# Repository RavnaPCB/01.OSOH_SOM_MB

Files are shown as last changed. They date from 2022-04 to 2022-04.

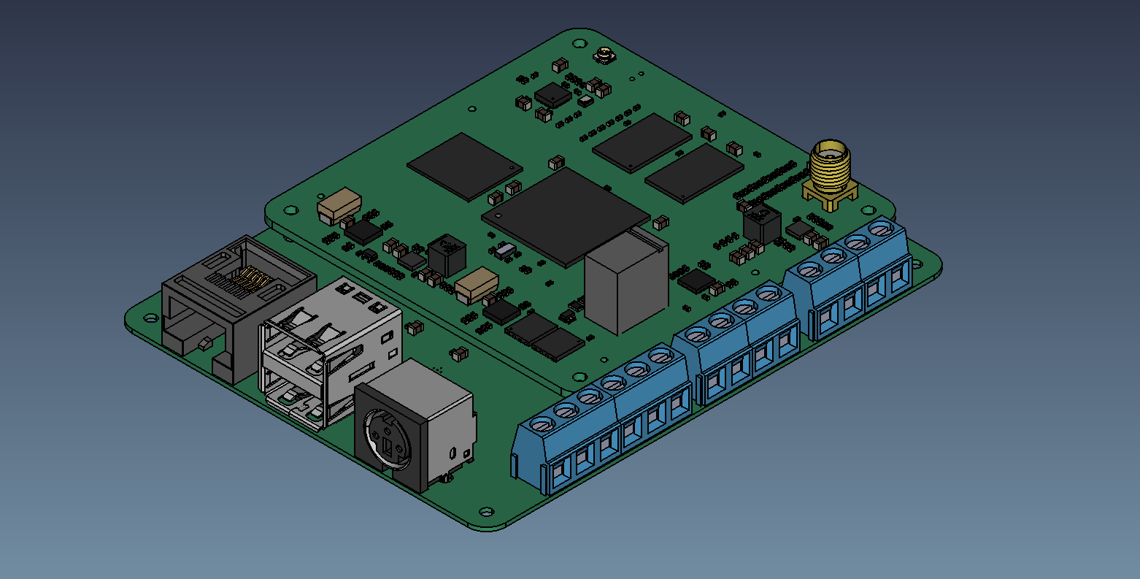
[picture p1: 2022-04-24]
1.3DCAD/Module_00.png

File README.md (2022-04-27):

## ReadME

    STM32MP157 SOM [DBSTM32MP1]               - [Work In Progress]
    
    STM32MP157 Motherboard [MB10080_STM32MP1] - [Work In Progress]
    
## Introduction

I started this project a few months ago, in order to learn PCB Design, and deepen my electronics knowledge, with the intention to eventually publicly release the development files, so other people could learn from them and my mistakes, and maybe at some point, after all the issues are sorted out - use as a reference or put to actual use.

## Future Plans

> Develop a series of robust [OpenHardware] Systems On Module [SOM], Motherboards and Single Board Computers [SBC] capable of operating in the industrial temperature range, accompanied by detailed circuit explanations, spreadsheets, simulations and repair manuals.

## Software Requirements [OpenSource]

[KiCAD](https://www.kicad.org/) - A Cross Platform and Open Source Electronics Design Automation Suite

[LibreOFFICE](https://www.libreoffice.org)  - Office Suite

[FreeCAD](https://www.freecadweb.org/)  - 3D Parametric Modeler

[FEMM](https://www.femm.info/wiki/Download) - Finite Element Method Magnetics

[CommonLIB](https://github.com/IvanIlievOSOH/00.CommonLIB) - Custom KiCAD Library

## Knows Issues, Flaws and Quirks

> The components I picked are not the best ones currently in production, nor the most suitable ones, but when I started this project a few months ago, I had the intention to get the PCBs manufactured and assembled, so I had to work with what was available on Mouser and Digikey, but since a complete redesign will be necessary to fix some of the issues and the ongoing chip shortage is still going strong, the next revision will be a major one, using other, more suitable components, not necessarily available at the moment from the official distributors. The boards will be manufactured and assembled when the semiconductor crisis is over unless I a way to source the components

> There are some things that don't make much sense at first glance (unused pads, holes in the solder mask, unnecessary components and copper pours etc). Most are there intentionaly because I wanted to do some measurements and experiments with the PCBs in order to prove some rules and concepts to myself.

> There are also some very obvious and probably critical "SI" and "PI" issues (Dual Stripline traces running parallel to eachother longer than they should, one of the eMMC Flash power rails routed as a relatively narrow trace on an outside layer etc.). I will be reporting and describing every issue I find in the repository's "Issues" tab.

> In hindsight, most of the issues and mistakes could have easily been avoided at an earlier stage of the design, if more research was done, but I decided to upload everything now, as a [Work In Progress], so I can hopefully get some constructive criticism and suggestoins before I start redesigning the boards.

    All your feedback, cirticism, help and suggestions will be greatly appreciated.



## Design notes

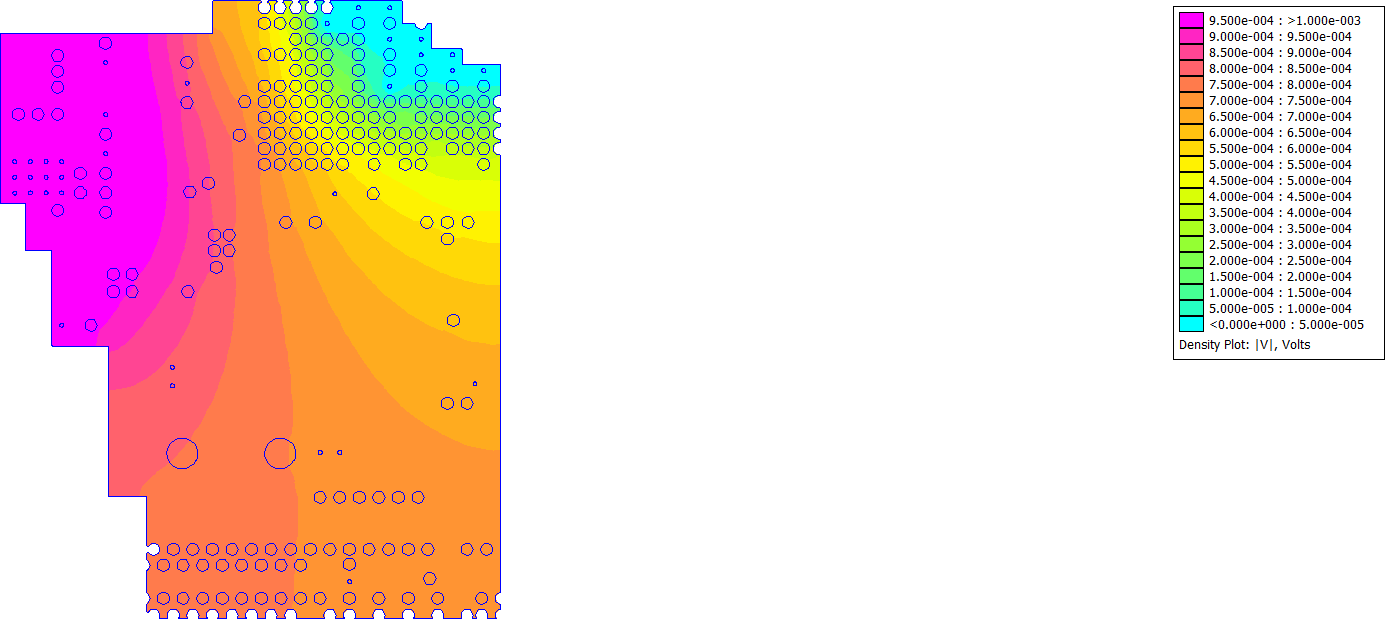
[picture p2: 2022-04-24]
1.DBSTM32MP1 [WIP]/Simulations/FEMM/VDD_CPU/Voltage_Drop.png

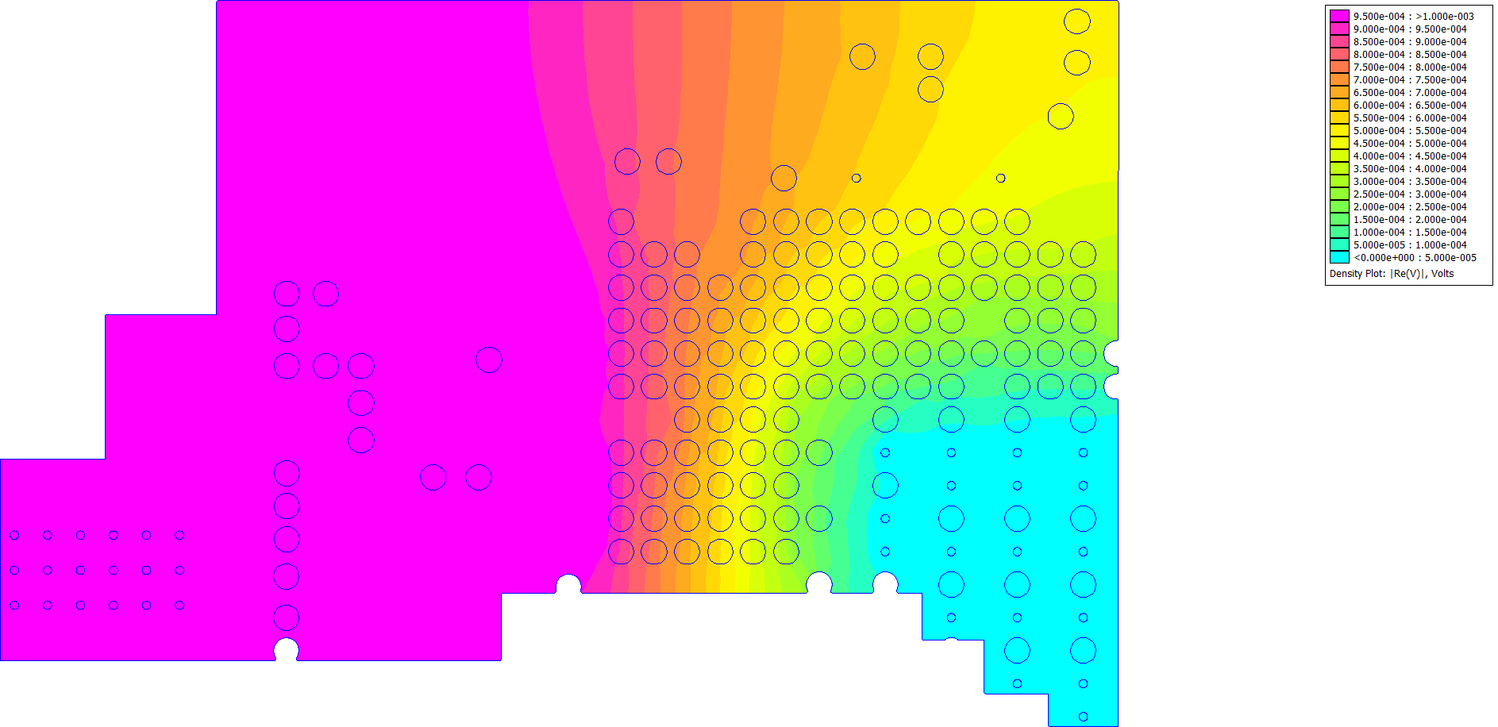
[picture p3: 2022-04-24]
1.DBSTM32MP1 [WIP]/Simulations/FEMM/VCORE/Voltage_Drop.png

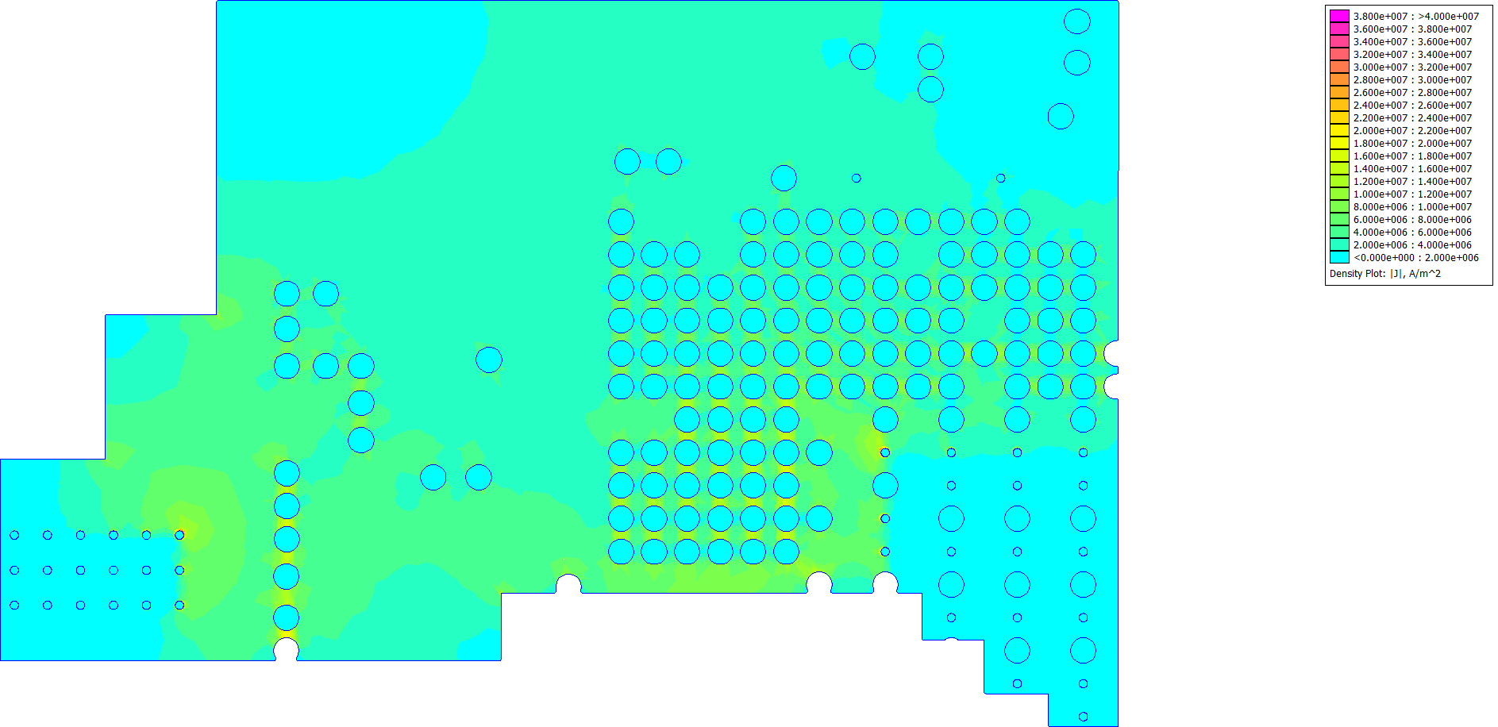
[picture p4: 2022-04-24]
1.DBSTM32MP1 [WIP]/Simulations/FEMM/VCORE/Current_Density.png

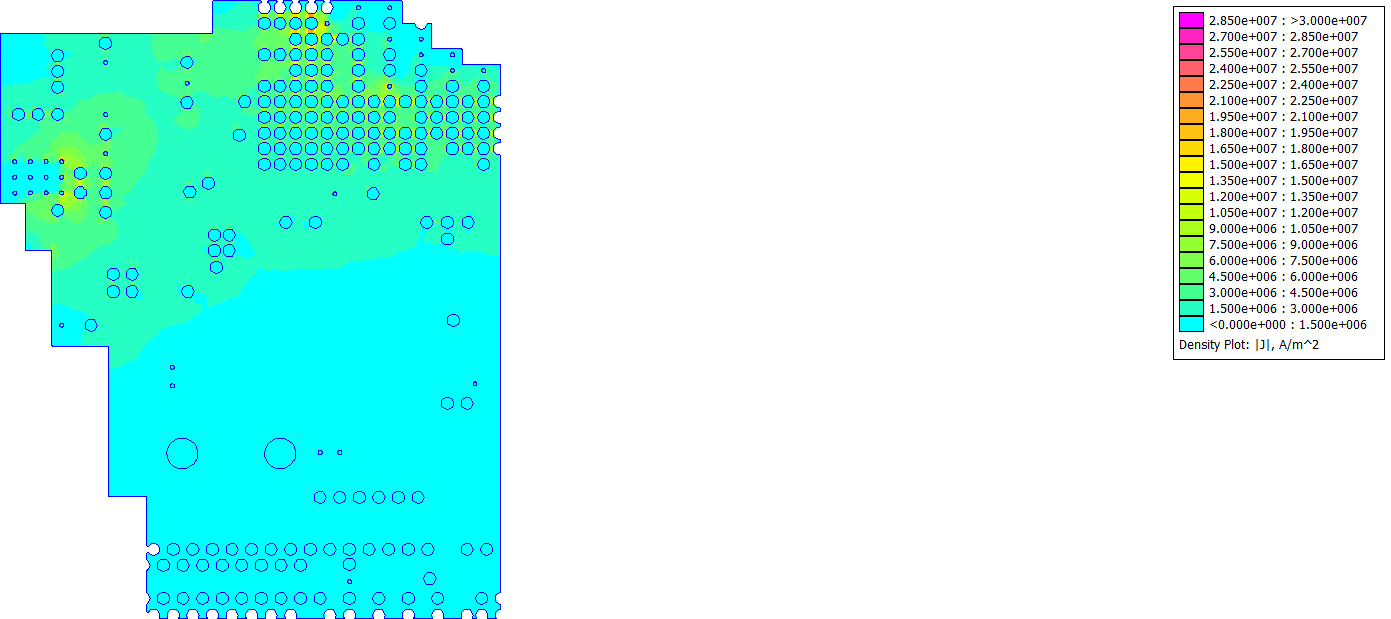
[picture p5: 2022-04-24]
1.DBSTM32MP1 [WIP]/Simulations/FEMM/VDD_CPU/Current_Density.png

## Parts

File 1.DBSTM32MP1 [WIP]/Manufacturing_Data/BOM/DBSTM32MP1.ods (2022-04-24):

Ref | Qnty | Value | Cmp name | Footprint | Description
C100, C101, C102, C103, C120, C140, C141, C241, C242, C243, C270, C271, C272, C273, C300, C301, C302, C306, C332, C502, C512, C532, C542, C543, C611, C641, C700, C710, C800, | 29 | 10uF | C | 00.Common:C_0805 | C
C104, C105, C106, C107, C108, C109, C110, C111, C112, C113, C114, C115, C116, C130, C131, C132, C133, C134, C135, C136, C142, C143, C144, C145, C146, C147, C148, C149, C150, C151, C152, C153, C154, C303, C304, C305, C307, C330, C331, C340, C400, C460, C462, C480, C520, C580, C601, C602, C612, C613, C642, C651, C701, C801, | 54 | 1uF | C | 00.Common:C_0402 | C
C200, C201, C202, C203, C204, C205, C206, C207, C208, C209, C210, C211, C212, C213, C220, C221, C222, C223, C224, C225, C226, C227, C228, C229, C230, C231, C232, C233, C240, C250, C251, C252, C253, C254, C255, C256, C257, C258, C259, C260, C261, C262, C263, C264, C265, C266, C267, C341, C350, C351, C352, C353, C354, C355, C356, C370, C371, C372, C373, C374, C375, C376, C377, C378, C379, C380, C381, C382, C383, C384, C385, C386, C387, C388, C389, C390, C391, C392, C393, C461, C470, C490, C491, C503, C504, C513, C514, C515, C521, C522, C533, C534, C544, C545, C546, C547, C581, C582, C603, C614, C615, C621, C643, C644, C652, C653, C702, C703, C704, C711, C712, C713, C714, C721, C751, C752, C760, C761, C780, C802, C803, C810, | 122 | 100nF | C | 00.Common:C_0402 | C
C310, C311, C820, C830, | 4 | C | C | 00.Common:C_0402 | C
C357, C360, | 2 | 2.2uF | C | 00.Common:C_0805 | C
C430, C431, | 2 | 6.8pF | C | 00.Common:C_0402 | C
C440, C620, C660, C720, C770, | 5 | 10nF | C | 00.Common:C_0402 | C
C450, | 1 | 47mF | CP | 00.Common:FM0H104ZF | CP
C500, C530, C540, | 3 | 22uF | CP | 00.Common:C_2312 | CP
C501, C510, C511, C531, C541, C610, C650, | 7 | 22uF | C | 00.Common:C_0805 | C
C523, C583, | 2 | 3.3nF | C | 00.Common:C_0402 | C
C600, C640, | 2 | 10uF | CP | 00.Common:C_2312 | CP
C750, | 1 | 4.7uF | C | 00.Common:C_0805 | C
D420, | 1 | RED | LED | 00.Common:LED_0402
D421, | 1 | BLUE | LED | 00.Common:LED_0402
D500, D530, | 2 | D | D | 00.Common:D_0402 | D
J1, J2, | 2 | Connector_1x2 | Connector_1x2 | 00.Common:1x02_Connector_2mm_Vertical_THT | Connector_1x2
J3, | 1 | Coax | Coax | 00.Common:CONUFL001-SMD-T | Connector_Coax
J4, | 1 | uSD | uSD | 00.Common:uSD_693072010801 | uSD
J5, | 1 | Coax | Coax | 00.Common:SMA_132134-10 | Connector_Coax
J6, J8, | 2 | FX10A-120S-P-SV | FX10A-120S-P-SV | 00.Common:FX10A-120S-P-SV | FX10A-120S-P-SV
J7, | 1 | Connector_2x5 | Connector_2x5 | 00.Common:2x05_Connector_1.00_Vertical_SMD | Connector_2x5
L300, | 1 | 4.7uH | L | 00.Common:C_0805 | L
L310, | 1 | L | L | 00.Common:C_0402 | L
L460, | 1 | 4.7uH | L | 00.Common:R_0805 | L
L500, L530, | 2 | 1.4uH | L | 00.Common:XGL_4040 | L
Q500, | 1 | N_MOSFET | N_MOSFET | 00.Common:SOT-323_SC-70
R200, R201, R202, R203, R204, R205, R206, R207, R208, R209, R210, R211, R212, R213, R214, R215, R216, R217, R218, R219, R220, R221, R222, R223, | 24 | 56R | R | 00.Common:R_0402 | R
R224, R225, R330, R340, R350, R351, R352, R353, R750, | 9 | 10K | R | 00.Common:R_0402 | R
R226, R620, | 2 | 100R | R | 00.Common:R_0402 | R
R240, R241, R242, | 3 | 240R | R | 00.Common:R_0402 | R
R300, | 1 | 50R | R | 00.Common:R_0402 | R
R331, R354, | 2 | 22R | R | 00.Common:R_0402 | R
R332, R355, R400, R402, R403, R405, R406, R408, R409, R410, R411, R412, R430, R431, R442, R470, R471, R500, R504, R640, R803, R900, | 22 | 0R | R | 00.Common:R_0402 | R
R401, R404, R407, R440, | 4 | 1K | R | 00.Common:R_0402 | R
R420, R421, | 2 | 220R | R | 00.Common:R_0402 | R
R441, | 1 | 10R | R | 00.Common:R_0402 | R
R450, R451, R452, R460, | 4 | 0R | R | 00.Common:R_0805 | R
R480, | 1 | 3K | R | 00.Common:R_0402 | R
R490, R491, R492, R493, R494, R495, | 6 | 1.5K | R | 00.Common:R_0402 | R
R501, R502, R503, R530, R531, R532, R621, R622, R641, R642, R721, R722, R751, R752, | 14 | 100K | R | 00.Common:R_0402 | R
R720, | 1 | R100 | R | 00.Common:R_0402 | R
R800, R801, | 2 | R | R | 00.Common:R_0402 | R
U1, U2, | 2 | RT6206 | RT6206 | 00.Common:WDFN-10L-3x3 | RT6206
U3, U4, U5, | 3 | LP38798 | LP38798 | 00.Common:WSON-12_4x4 | LP38798
U6, | 1 | LP3878-ADJ | LP3878-ADJ | 00.Common:WSON-8-4x4 | LP3878
U7, | 1 | LP2998 | LP2998 | 00.Common:DFN-10-1EP_3x3 | LP2998
U8, | 1 | WF200SD | WF200SD | 00.Common:QFN-32-4x4-P0.4 | WF200SD
U9, U16, | 2 | DDR3L | DDR3L | 00.Common:TF_BGA96
U10, U11, | 2 | WSON-8-6x5-FLASH | WSON-8-6x5-FLASH | 00.Common:WSON-8-6x5 | WSON-8-6x5-FLASH
U12, | 1 | STM32MP157AAA3 | STM32MP1_BASE | 00.Common:STM32MP157AAA3 | STM32MP1_BASE
U13, U14, | 2 | AND_GATE | AND_GATE | 00.Common:SOT-353_SC-70-5 | AND_GATE
U15, | 1 | eMMC | eMMC | 00.Common:WFBGA153 | eMMC
X1, | 1 | 24.00 MHz | MEMS_OSC | 00.Common:OSC-3.2x2.5
Y2, | 1 | 32.768 KHz | 2P_OSC | 00.Common:OSC-3.2x1.5 | 2P_OSC
Y300, | 1 | 38.4 MHz | OSC_GND24 | 00.Common:OSC_2.0x1.6 | OSC_GND24

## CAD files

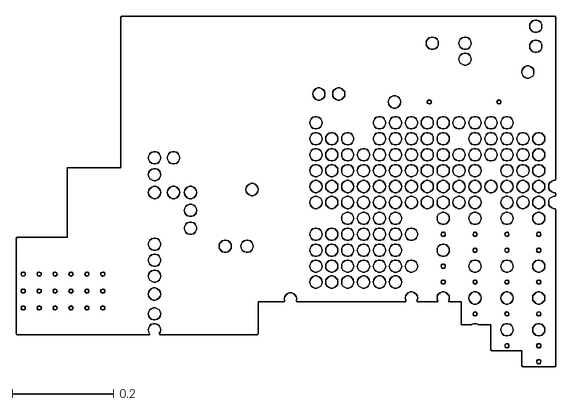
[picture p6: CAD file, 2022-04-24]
1.DBSTM32MP1 [WIP]/Simulations/DXF/DBSTM32MP1-VDD_CORE.dxf
1.07 x 0.693

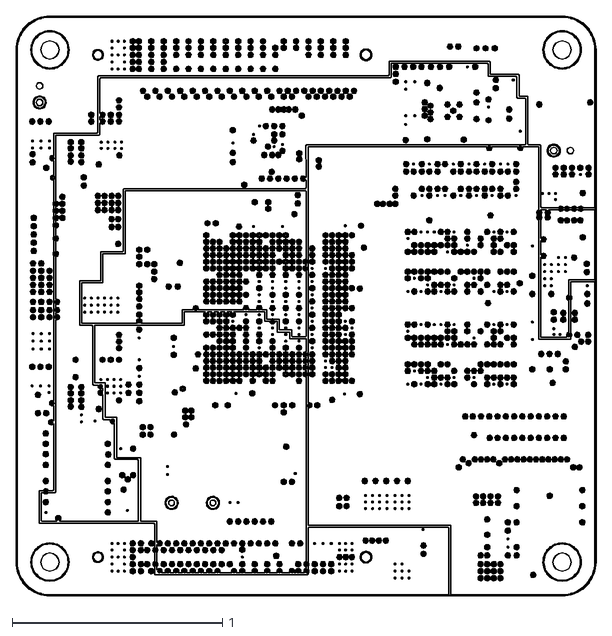
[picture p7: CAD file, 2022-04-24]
1.DBSTM32MP1 [WIP]/Simulations/DXF/DBSTM32MP1-VDD[RAW].dxf
2.76 x 2.76

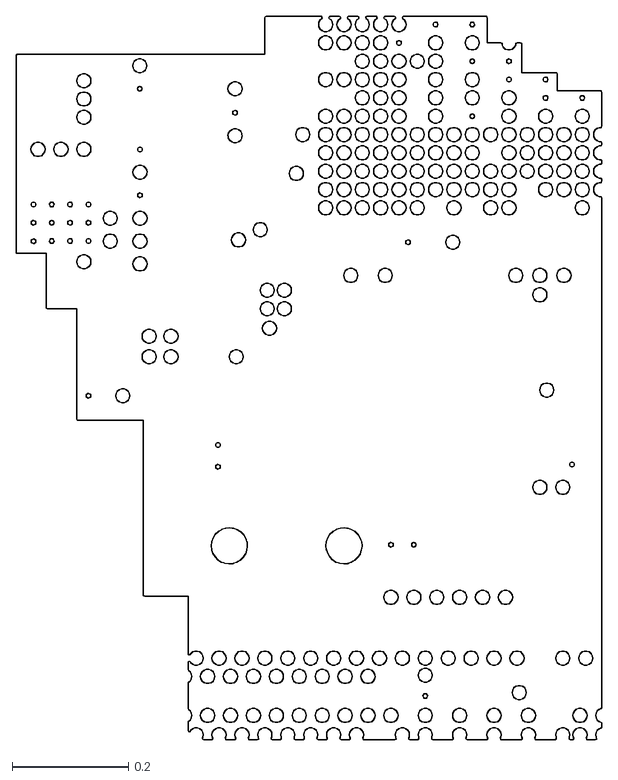
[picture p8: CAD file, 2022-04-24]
1.DBSTM32MP1 [WIP]/Simulations/DXF/DBSTM32MP1-VDD_CPU.dxf
1.01 x 1.24

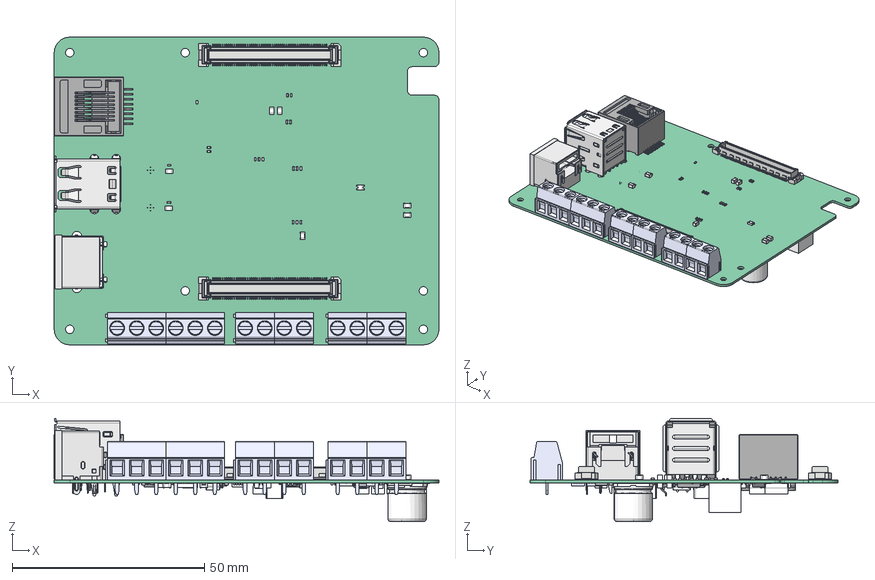
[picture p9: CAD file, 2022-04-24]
1.MB10080_STM32MP1 [WIP]/3DCAD/MB10080_STM32MP1.FCStd
100.1 x 80.0 x 26.8 mm
Pcb_820f
TB006-508-03P_Blue - S
TB006-508-03P_Blue - S001
C95_C_0402_1005Metric_89083f15f6f9
R26_R_0402_1005Metric_b49b6816676e
C103_C_0805_2012Metric_27ec9a05496c
C97_C_0805_2012Metric_ac6420e91872
R24_R_0402_1005Metric_b9c2278e08e6
C73_C_0402_1005Metric_77ea594f8db1
C101_C_0402_1005Metric_fdc04734f633
C30_C_0402_1005Metric_dc666e8bfdf3
TB006-508-02P_Blue - S
TB006-508-02P_Blue - S001
C99_C_0402_1005Metric_8ebc8eb86d38
C89_C_0402_1005Metric_ad1054f418c5
C12_C_0805_2012Metric_cb829bac7224
C27_C_0402_1005Metric_738307f9e339
C87_C_0402_1005Metric_293bc573aa11
C111_C_0805_2012Metric_cfe71d9d4230
J8_FX10A-120P-SV_b29a9b1ca1f1
C114_C_0402_1005Metric_6f66377c607f
CUI_DEVICES_MD-30SM
CUI_DEVICES_MD-30SM001
CUI_DEVICES_MD-30SM002
CUI_DEVICES_MD-30SM003
CUI_DEVICES_MD-30SM004
CUI_DEVICES_MD-30SM005
C96_C_0805_2012Metric_dac484ff7f15
C115_C_0402_1005Metric_cd8c7d194291
C88_C_0805_2012Metric_c22c037c54e6
TB006-508-02P_Blue - S002
TB006-508-02P_Blue - S003
J9_(Unsaved)_836c44e12b4a
D2_D_0805_3bacf84006ee
C94_C_0402_1005Metric_d5e17bd9bb97
C106_C_0402_1005Metric_816197e5a8a8
(Unsaved)
(Unsaved)001
(Unsaved)002
(Unsaved)003
(Unsaved)004
(Unsaved)005
(Unsaved)006
(Unsaved)007
(Unsaved)008
(Unsaved)009
(Unsaved)010
(Unsaved)011
(Unsaved)012
(Unsaved)013
(Unsaved)014
(Unsaved)015
(Unsaved)016
(Unsaved)017
(Unsaved)018
(Unsaved)019
C113_C_0402_1005Metric_2f24029c02ec
C71_C_0402_1005Metric_c18872e2a6e8
R25_R_0402_1005Metric_be235fa08f4c
C36_C_0402_1005Metric_1dce11c8cb39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

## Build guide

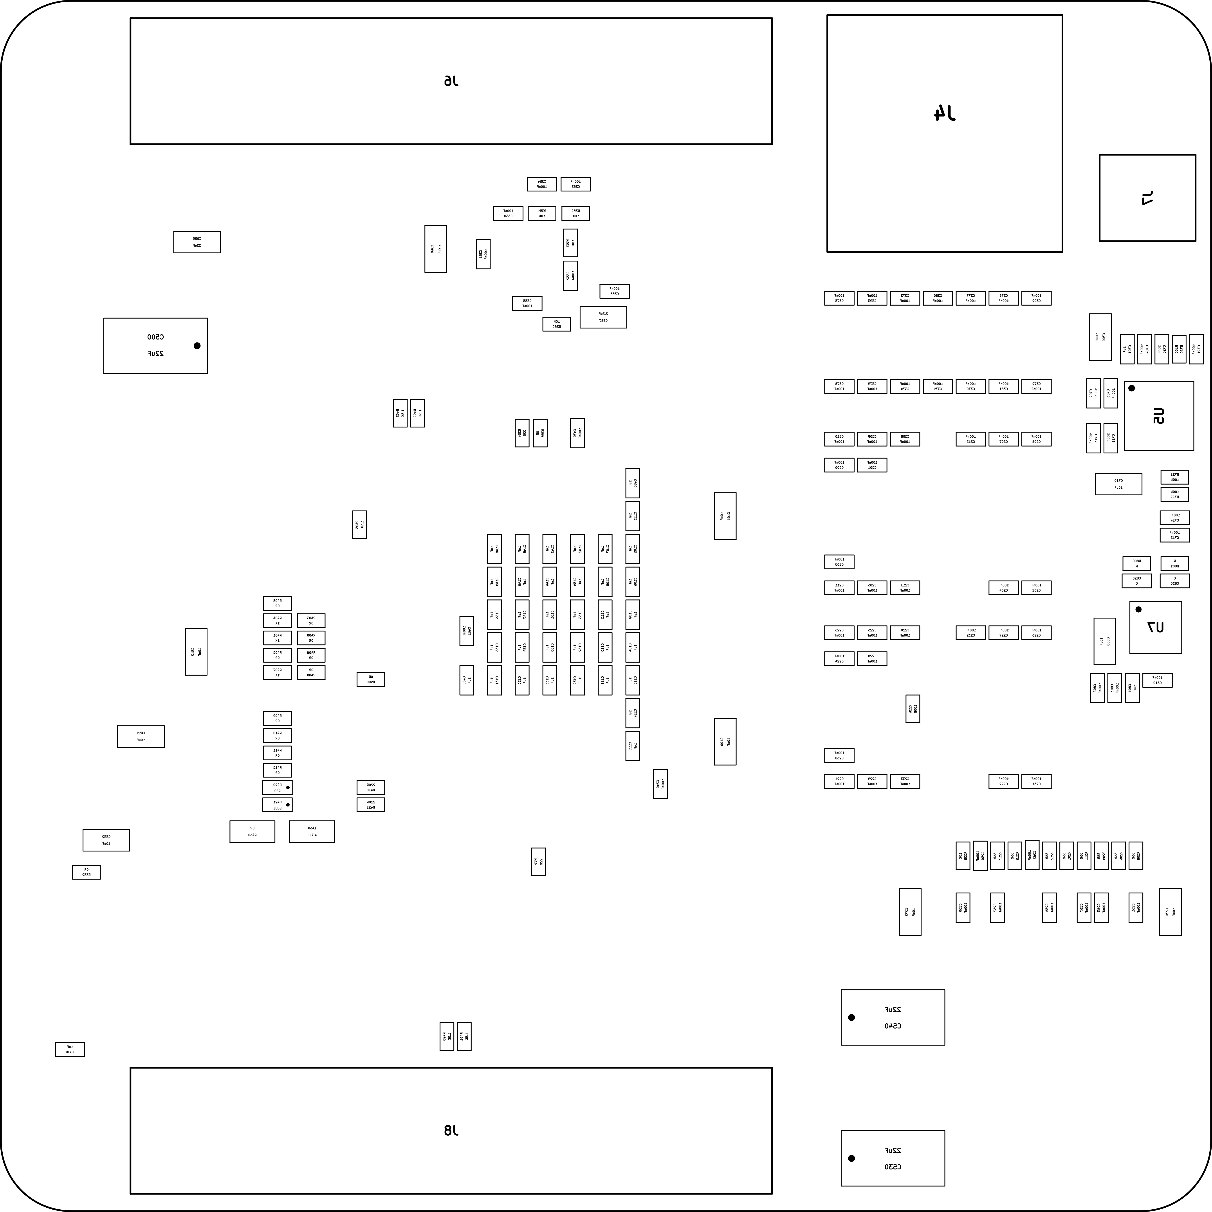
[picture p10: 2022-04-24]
1.DBSTM32MP1 [WIP]/Manufacturing_Data/ASSEMBLY/DBSTM32MP1-B_Fab.png

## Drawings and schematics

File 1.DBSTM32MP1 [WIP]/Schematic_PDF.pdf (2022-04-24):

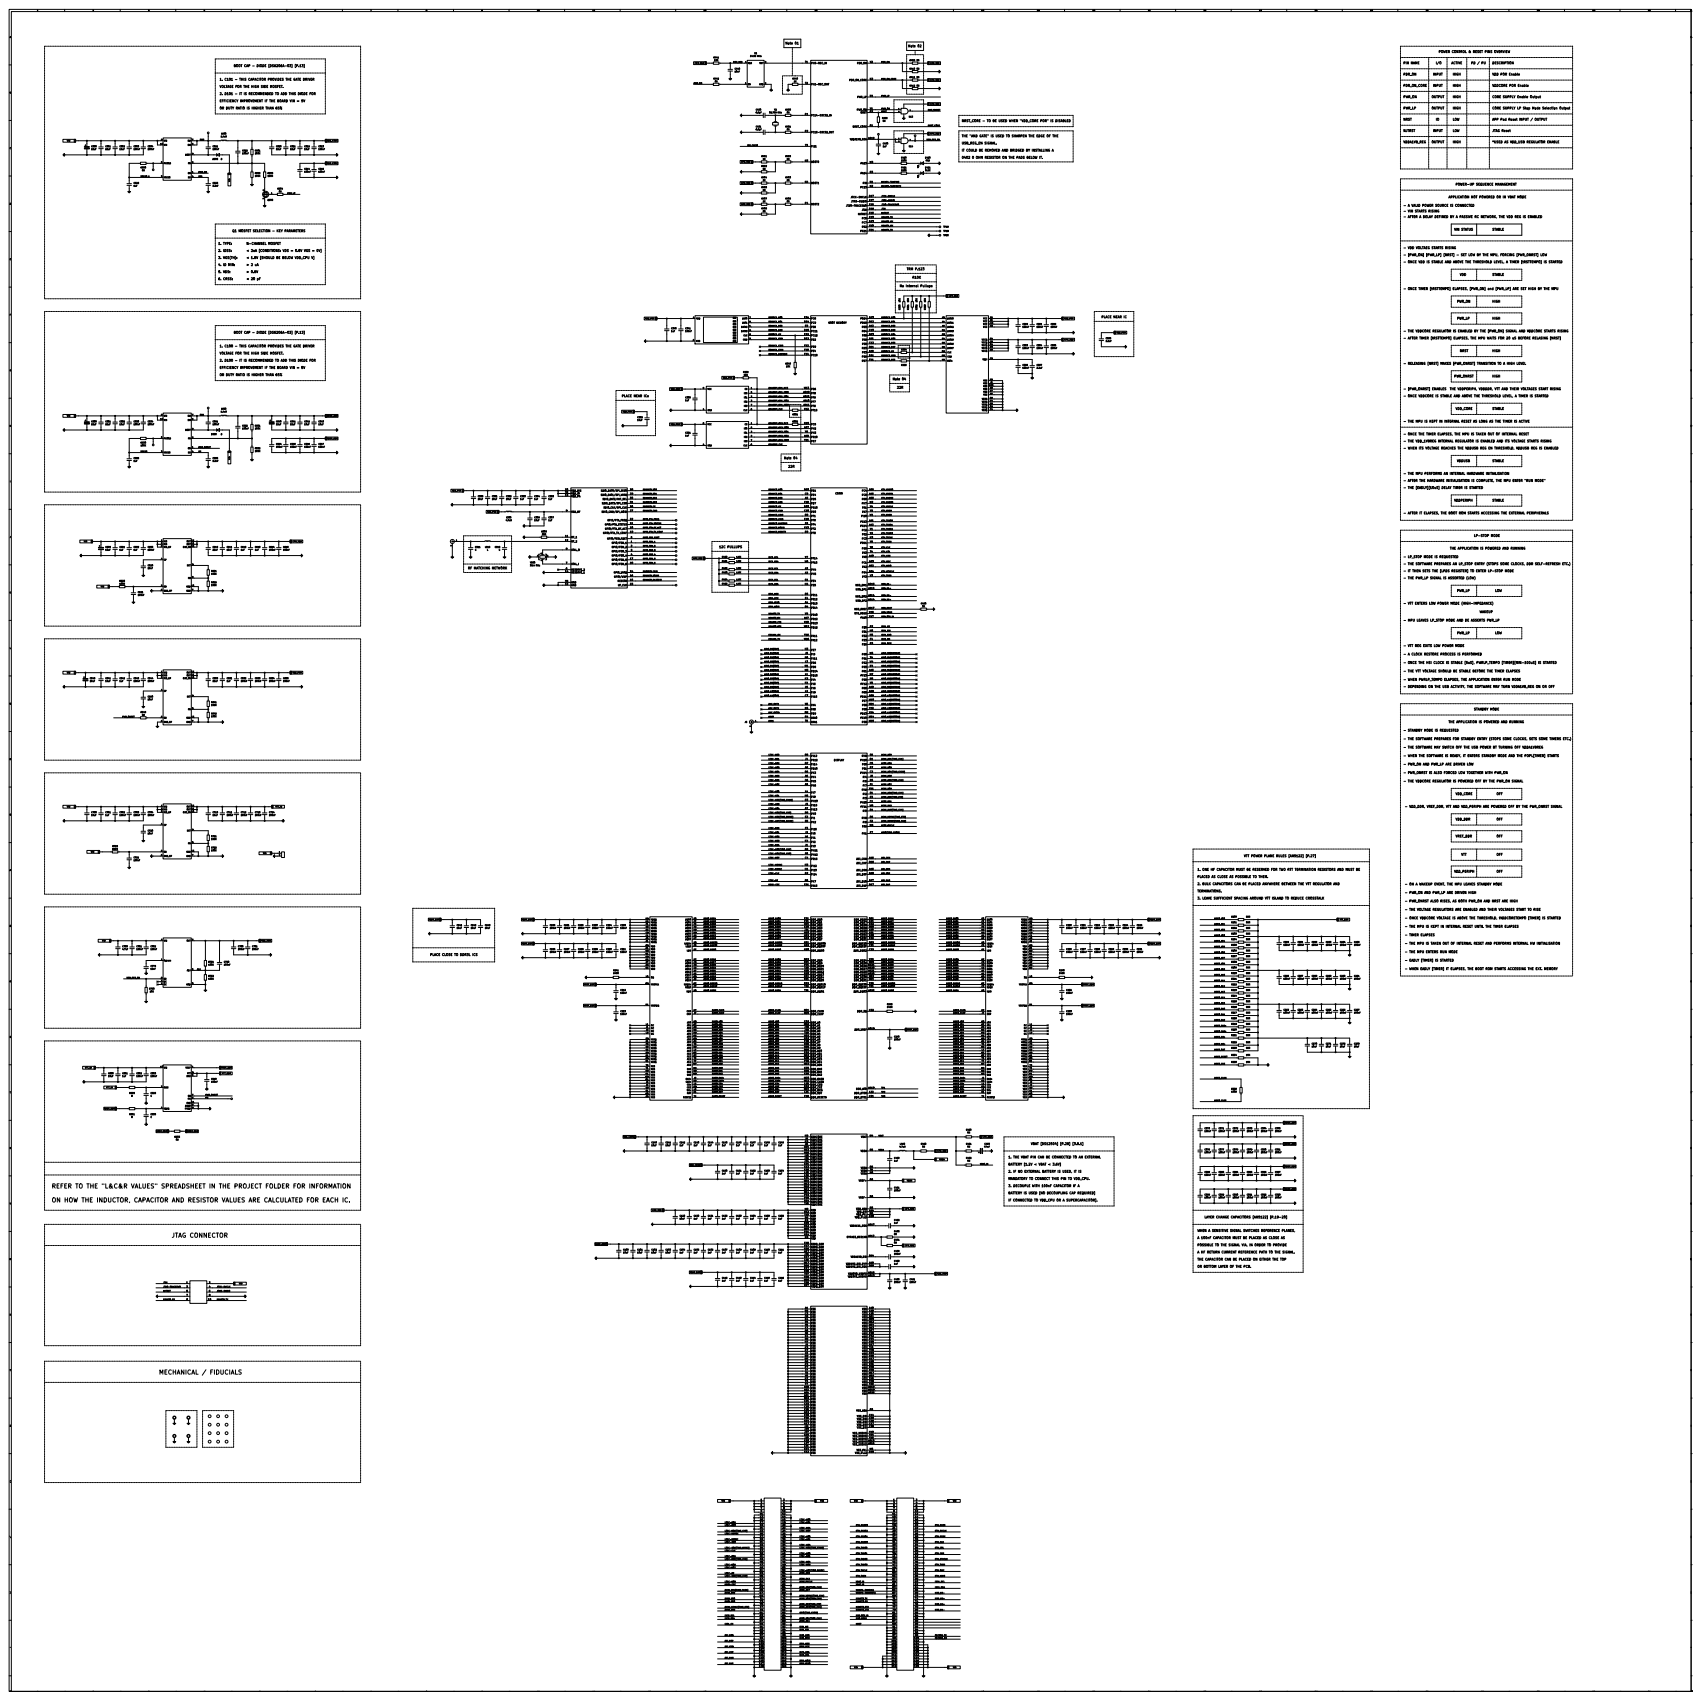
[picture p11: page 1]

POWER CONTROL & RESET PINS OVERVIEW

1. C101 - THIS CAPACITOR PROVIDES THE GATE DRIVER

VOLTAGE FOR THE HIGH SIDE MOSFET.

2. D101 - IT IS RECOMMENDED TO ADD THIS DIODE FOR

CORE SUPPLY Enable Output

EFFICIENCY IMPROVEMENT IF THE BOARD VIN = 5V

OR DUTY RATIO IS HIGHER THAN 65%

CORE SUPPLY LP Stop Mode Selection Output

APP Pad Reset INPUT / OUTPUT

NRST_CORE - TO BE USED WHEN "VDD_CORE POR" IS DISABLED

THE "AND GATE" IS USED TO SHARPEN THE EDGE OF THE

*USED AS VDD_USB REGULATOR ENABLE

IT COULD BE REMOVED AND BRIDGED BY INSTALLING A

0402 0 OHM RESISTOR ON THE PADS BELOW IT.

POWER-UP SEQUENCE MANAGEMENT

APPLICATION NOT POWERED OR IN VBAT MODE

- A VALID POWER SOURCE IS CONNECTED
- VIN STARTS RISING
- AFTER A DELAY DEFINED BY A PASSIVE RC NETWORK, THE VDD REG IS ENABLED

Q1 MOSFET SELECTION - KEY PARAMETERS

- VDD VOLTAEG STARTS RISING

- ONCE VDD IS STABLE AND ABOVE THE THRESHOLD LEVEL, A TIMER [tRSTTEMPO] IS STARTED

- ONCE TIMER [tRSTTEMPO] ELAPSES, [PWR_ON] and [PWR_LP] ARE SET HIGH BY THE MPU

- THE VDDCORE REGULATOR IS ENABLED BY THE [PWR_ON] SIGNAL AND VDDCORE STARTS RISING
- AFTER TIMER [tRSTTEMPO] ELAPSES, THE MPU WAITS FOR 20 uS BEFORE RELASING [NRST]

1. C100 - THIS CAPACITOR PROVIDES THE GATE DRIVER

2. D100 - IT IS RECOMMENDED TO ADD THIS DIODE FOR

- RELEASING [NRST] MAKES [PWR_ONRST] TRANSITION TO A HIGH LEVEL

- [PWR_ONRST] ENABLES THE VDDPERIPH, VDDDDR, VTT AND THEIR VOLTAGES START RISING
- ONCE VDDCORE IS STABLE AND ABOVE THE THRESHOLD LEVEL, A TIMER IS STARTED

- THE MPU IS KEPT IN INTERNAL RESET AS LONG AS THE TIMER IS ACTIVE

- ONCE THE TIMER ELAPSES, THE MPU IS TAKEN OUT OF INTERNAL RESET
- THE VDD_1V8REG INTERNAL REGULATOR IS ENABLED AND ITS VOLTAGE STARTS RISING
- WHEN ITS VOLTAGE REACHES THE VDDUSB REG EN THRESHOLD, VDDUSB REG IS ENABLED

- THE MPU PERFORMS AN INTERNAL HARDWARE INITIALISATION
- AFTER THE HARDWARE INITIALISATION IS COMPLETE, THE MPU ENTER "RUN MODE"
- THE [EADLY][10uS] DELAY TIMER IS STARTED

- AFTER IT ELAPSES, THE BOOT ROM STARTS ACCESSING THE EXTERNAL PERIPHERALS

THE APPLICATION IS POWERED AND RUNNING

- LP_STOP MODE IS REQUESTED
- THE SOFTWARE PREPARES AN LP_STOP ENTRY (STOPS SOME CLOCKS, DDR SELF-REFRESH ETC.)
- IT THEN SETS THE [LPDS REGISTER] TO ENTER LP-STOP MODE
- THE PWR_LP SIGNAL IS ASSERTED (LOW)

- VTT ENTERS LOW POWER MODE (HIGH-IMPEDANCE)

- MPU LEAVES LP_STOP MODE AND DE ASSERTS PWR_LP

- VTT REG EXITS LOW POWER MODE

- A CLOCK RESTORE PROCESS IS PERFORMED

- ONCE THE HSI CLOCK IS STABLE [5uS], PWRLP_TEMPO [TIMER][MIN-100uS] IS STARTED

- THE VTT VOLTAGE SHOULD BE STABLE BEFORE THE TIMER ELAPSES

- WHEN PWRLP_TEMPO ELAPSES, THE APPLICATION ENTER RUN MODE
- DEPENDING ON THE USB ACTIVITY, THE SOFTWARE MAY TURN VDDA1V8_REG ON OR OFF

- STANDBY MODE IS REQUESTED

- THE SOFTWARE PREPARES FOR STANDBY ENTRY (STOPS SOME CLOCKS, SETS SOME TIMERS ETC.)

- THE SOFTWARE MAY SWITCH OFF THE USB POWER BT TURNING OFF VDDA1V8REG

- WHEN THE SOFTWARE IS READY, IT ENTERS STANDBY MODE AND THE POPL[TIMER] STARTS

- PWR_ON AND PWR_LP ARE DRIVEN LOW

- PWR_ONRST IS ALSO FORCED LOW TOGETHER WITH PWR_ON

- THE VDDCORE REGULATOR IS POWERED OFF BY THE PWR_ON SIGNAL

- VDD_DDR, VREF_DDR, VTT AND VDD_PERIPH ARE POWERED OFF BY THE PWR_ONRST SIGNAL

VTT POWER PLANE RULES [AN5122] [P.27]

1. ONE HF CAPACITOR MUST BE RESERVED FOR TWO RTT TERMINATION RESISTORS AND MUST BE

PLACED AS CLOSE AS POSSIBLE TO THEM.

2. BULK CAPACITORS CAN BE PLACED ANYWHERE BETWEEN THE VTT REGULATOR AND

- ON A WAKEUP EVENT, THE MPU LEAVES STANDBY MODE

- PWR_ON AND PWR_LP ARE DRIVEN HIGH

3. LEAVE SUFFICIENT SPACING AROUND VTT ISLAND TO REDUCE CROSSTALK

- PWR_ONRST ALSO RISES, AS BOTH PWR_ON AND NRST ARE HIGH

- THE VOLTAGE REGULATORS ARE ENABLED AND THEIR VOLTAGES START TO RISE

- ONCE VDDCORE VOLTAGE IS ABOVE THE THRESHOLD, tVDDCORETEMPO [TIMER] IS STARTED

- THE MPU IS KEPT IN INTERNAL RESET UNTIL THE TIMER ELAPSES

- THE MPU IS TAKEN OUT OF INTERNAL RESET AND PERFORMS INTERNAL HW INITIALISATION

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

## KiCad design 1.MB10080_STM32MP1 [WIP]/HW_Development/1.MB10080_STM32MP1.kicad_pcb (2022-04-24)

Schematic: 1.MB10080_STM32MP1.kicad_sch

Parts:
C1, C2, C3, C4, C5, C6, C7, C8, C9, C10, C11, C13, C15, C16, C18, C19, C20, C21, C22, C23, C26, C27, C28, C29, C30, C33, C34, C37, C38, C39, C44, C45, C47, C48, C49, C53, C54, C55, C56, C57, C58, C59, C60, C61, C62, C63, C64, C65, C70, C71, C72, C73, C74, C78, C79, C80, C84, C85, C86, C87, C90, C91, C92, C93, C94, C95, C98, C99, C100, C101, C106, C113, C114, C115, C116, C117, C118, C119, C131, C132, C133, C137, C138, C139, C140, C141: 0.1uF; C_0402
C12, C31, C35, C88: 47uF; C_0805
C14: 220uF; CP_10x10
C17, C24, C25, C46, C50, C51, C52, C68, C69, C76, C77, C83, C96, C97, C104, C105, C111, C112, C134, C135: 0.1uF; C_0805
C32, C36, C89: 10uF; C_0402
C40, C41, C42, C43, C66, C67, C81, C82: C; C_0402
C75: 0.1uF; CP_2312
C102, C103: 1uF; C_0805
C122, C123, C124: 100uF; CP_2312
D2: D; D_0805
D6, D8: D
H1, H2, H3, H4, H5, H6, H7: MountingHole_Pad; MountingHole-[2.2]-PAD-M2
J1, J7: Connector_1x4; CUI_TB006-508-04BE
J2: Connector_1x6; CUI_TB006-508-06BE
J3: Connector_1x6; CUI_MD-30SM
J5: USB_A_Stacked; AU-Y1008-2
J6, J8: FX10A-120S-P-SV
J9: 8P8C_0955016890; 0955016890
L1, L9: 4.7uH; XGL-4040
L2, L3, L4, L5, L6, L7: L; L_0805
L100: 4.7uH; XAL-8080
Q1, Q2: SiSS76LDN; PowerPAK-1212-8S
Q5, Q6: CSD17327Q5A; SON-[5x6]
R1, R2, R3, R4, R5, R6, R7, R8, R11, R12, R14, R15, R17, R18, R27, R28, R29, R30, R33, R34, R39, R40: R; R_0402
R9: 0R; R_2512
R10, R13, R16, R19, R20, R21, R22, R23, R32, R38: 0R; R_0402
R24, R25, R26, R31: 0.007; R_0402
TP1, TP2, TP6, TP7, TP9, TP10: TP; TP-[R0402-PAD]
U1: LM3150; HTSSOP-14-[4.4x5]-[P0.65]
U2: LTC4368; MSOP-10-[3x3]-[P0.5]
U3, U13: RT6206; WDFN-10L-[3x3]-[P0.5]
U4: DS90UR905QSQ/NOPB; WQFN-48-[P0.5]
U5: LM3526; SOIC-08-[13.9x4.9]-[P1.27]
U6, U7: TUSB213; VQFN-14
U8: DP83TD510ERHBR; QFN-32-[5x5]-[P0.5]
U9: LP38798; WSON-12-[4x4]-[P0.5]
U11: DS15BA101; WSON-08-[3x3]-[P0.5]
U12: TJA1042; HVSON-8-[3x3]-[P0.65]
Y1: 2P_OSC

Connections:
1V8: C50.2, C51.2, C52.2, C53.2, C54.2, C55.2, C63.2, C64.2, C65.2, C68.2, C69.2, C70.2, C71.2, C72.2, C73.2, L5.1, L6.1, L7.1, R24.1, U4.24 (VODSEL), U9.10 (OUT_FB), U9.11 (OUT), U9.12 (OUT)
3V3: C18.2, C23.2, C24.2, C25.2, C26.2, C27.2, C28.2, C29.2, C30.2, C46.2, C75.2, C76.2, C77.2, C78.2, C79.2, C80.2, C83.2, C84.2, C85.2, C87.2, C90.2, C92.2, C93.2, C94.2, C95.2, C96.2, C97.2, L1.2, L2.1, L3.1, L4.1, R17.1, R19.2, R29.1, R30.1, R31.2, U9.1 (VIN), U9.2 (VIN), U9.3 (VIN_CP), U11.5 (VCC)
5V: C12.2, C36.2, C88.2, C89.2, C133.2, C134.2, C135.2, C137.2, C138.2, C139.2, C140.2, C141.2, L9.2, R11.1, R14.1, R39.1, U6.12 (VCC), U7.12 (VCC)
/DCMI_D00: J6.49
/DCMI_D01[TIM5_CH1]: J6.36
/DCMI_D02: J6.53
/DCMI_D03: J6.47
/DCMI_D04[TIM8_CH2N]: J6.55
/DCMI_D05: J6.68
/DCMI_D06[TIM8_CH2]: J6.58
/DCMI_D07: J6.56
/DCMI_D08: J6.41
/DCMI_D09[TIM8_CH4]: J6.50
/DCMI_D10[TIM8_ETR]: J6.46
/DCMI_D11: J6.34
/DCMI_D12: J6.64
/DCMI_D13[TIM5_CH4]: J6.44
/DCMI_HSYNC[TIM5_ETR]: J6.43
/DCMI_PXCLK: J6.62
/DCMI_VSYNC[TIM8_CH1]: J6.52
/DSI_CKN: J6.15
/DSI_CKP: J6.11
/DSI_D0N: J6.23
/DSI_D0P: J6.19
/DSI_D1N: J6.7
/DSI_D1P: J6.3
/EN: C1.2, U1.3 (EN)
/ETH_CLK: J8.90
/ETH_COL: J8.86
/ETH_CRS: J8.82
/ETH_GTXCLK: J8.78
/ETH_MDC: J8.70
/ETH_MDIO: J8.66
/ETH_RXCLK: J8.98
/ETH_RXD00: J8.89
/ETH_RXD01: J8.93
/ETH_RXD02: J8.97
/ETH_RXD03: J8.101
/ETH_RXDV: J8.94
/ETH_RXER: J8.102
/ETH_TXCLK: J8.69
/ETH_TXD00: J8.85
/ETH_TXD01: J8.81
/ETH_TXD02: J8.77
/ETH_TXD03: J8.73
/ETH_TXEN: J8.65
/ETH_TXER: J8.74
/FAULT: U2.7 (FAULT)
/FB: C5.1, C7.1, R4.2, R5.2, U1.4 (FB)
/FDCAN1_RX: J8.34
/FDCAN1_TX: J8.36
/GATE: U2.10 (GATE)
/GPIO[TIM8_CH3N]: J6.40
/HDMI-CEC: J6.59
/I2C1_SCL: J8.62
/I2C1_SDA: J8.58
/I2C2_SCL: J6.37
/I2C2_SDA: J6.35
/I2C4_SCL: J6.10
/I2C4_SDA: J6.12
/I2S1_CK: J6.31
/I2S1_MCK: J6.22
/I2S1_SDI: J6.28
/I2S1_SDO: J6.24
/I2S1_WS: J6.30
/LTDC-B00: J6.82, U4.43 (B0)
/LTDC-B01: J6.80, U4.44 (B1)
/LTDC-B02: J6.79, U4.45 (B2)
/LTDC-B03: J6.61, U4.46 (B3)
/LTDC-B04: J6.76, U4.47 (B4)
/LTDC-B05: J6.74, U4.48 (B5)
/LTDC-B06: J6.73, U4.1 (B6)
/LTDC-B07: J6.71, U4.2 (B7)
/LTDC-CLK: J6.83, U4.10 (PCLK)
/LTDC-DE: J6.67, U4.5 (DE)
/LTDC-G00: J6.94, U4.35 (G0)
/LTDC-G01: J6.92, U4.36 (G1)
/LTDC-G02[TIM8_CH1N]: J6.86, U4.37 (G2)
/LTDC-G03: J6.89, U4.38 (G3)
/LTDC-G04: J6.88, U4.39 (G4)
/LTDC-G05[TIM8_CH3]: J6.65, U4.40 (G5)
/LTDC-G06[TIM8_BKIN2]: J6.85, U4.41 (G6)
/LTDC-G07[TIM8_BKIN1]: J6.70, U4.42 (G7)
/LTDC-HSYNC: J6.95, U4.3 (HS)
/LTDC-R00: J6.106, U4.25 (R0)
/LTDC-R01: J6.104, U4.26 (R1)
/LTDC-R02: J6.103, U4.27 (R2)
/LTDC-R03: J6.101, U4.28 (R3)
/LTDC-R04: J6.100, U4.29 (R4)
/LTDC-R05[TIM5_CH2]: J6.77, U4.32 (R5)
/LTDC-R06[TIM5_CH3]: J6.97, U4.33 (R6)
/LTDC-R07: J6.98, U4.34 (R7)
/LTDC-VSYNC: J6.91, U4.4 (VS)
/NRST: J8.31
/OV: C15.2, R7.2, R8.1, TP2.1, U2.3 (OV)
/RETRY: C16.2, U2.4 (RETRY)
/RX+: R21.1, U8.5 (RX+)
/RX-: R23.1, U8.6 (RX-)
/SENSE: R9.1, U2.9 (SENSE)
/SHDN: U2.6 (SHDN)
/SPI4_MISO: J6.4
/SPI4_MOSI: J6.6
/SPI4_NSS: J6.18
/SPI4_SCK: J6.16
/SW: C3.1, C21.2, C131.2, L1.1, L9.1, L100.1, R2.1, R3.1, TP7.1, TP10.1, U1.10 (SW), U3.6 (SW), U3.7 (SW), U13.6 (SW), U13.7 (SW)
/TX+: R20.1, U8.4 (TX+)
/TX-: R22.1, U8.7 (TX-)
/USART3_CTS: J8.41
/USART3_RTS: J8.43
/USART3_RX: J8.47
/USART3_TX: J8.49
/USB_D1+: J8.46
/USB_D1-: J8.42
/USB_D2+: J8.50
/USB_D2-: J8.54
/USB_OTG_ID: J8.37
/USB_VBUS: J8.35
/UV: C13.2, R6.2, R7.1, TP1.1, U2.2 (UV)
/VBAT_IN: J8.59, J8.61
/VCC_DCDC: C4.2, D2.2 (A), U1.1 (VCC)
/VDDA: C31.2, C32.2, C33.2, C34.2, L2.2, U8.3 (VDDA_3V3)
/VDDIO: C35.2, C37.2, C38.2, C48.2, C49.2, L3.2, L4.2, U4.30 (VDDIO), U8.17 (VDDIO)
/VDDL: C57.2, C60.2, L6.2, U4.7 (VDDL)
/VDDP: C58.2, C61.2, L7.2, U4.14 (VDDP)
/VDDTXHS: C56.2, C59.2, L5.2, U4.17 (VDDHS), U4.22 (VDDTX)
/WKUP3-TAMPOUT2: J8.53
/WKUP4-TAMPIN2: J8.55
DCDCOUT: C6.2, C7.2, C17.2, C20.2, C74.2, C86.2, C99.2, C101.2, C106.2, C111.2, C112.2, C113.2, C114.2, C115.2, C116.2, C117.2, C119.2, C122.1, C123.1, C124.1, D6.2 (A), D8.2 (A), J6.111, J6.112, J6.113, J6.114, J6.115, J6.116, J6.117, J6.118, J6.119, J6.120, J8.1, J8.2, J8.3, J8.4, J8.5, J8.6, J8.7, J8.8, J8.9, J8.10, J8.12, J8.14, J8.16, J8.18, J8.20, J8.22, J8.111, J8.112, J8.113, J8.114, J8.115, J8.116, J8.117, J8.118, J8.119, J8.120, L100.2, R4.1, U3.9 (VIN), U3.10 (VIN), U13.9 (VIN), U13.10 (VIN)
GND: C1.1, C2.1, C4.1, C8.1, C9.1, C10.1, C11.1, C12.1, C13.1, C14.2, C15.1, C16.1, C17.1, C18.1, C19.1, C20.1, C22.1, C24.1, C25.1, C26.1, C27.1, C28.1, C29.1, C30.1, C31.1, C32.1, C33.1, C34.1, C35.1, C36.1, C37.1, C38.1, C39.1, C40.2, C41.2, C44.1, C45.1, C46.1, C47.1, C48.1, C49.1, C50.1, C51.1, C52.1, C53.1, C54.1, C55.1, C56.1, C57.1, C58.1, C59.1, C60.1, C61.1, C62.1, C63.1, C64.1, C65.1, C68.1, C69.1, C70.1, C71.1, C72.1, C73.1, C74.1, C75.1, C76.1, C77.1, C78.1, C79.1, C80.1, C83.1, C84.1, C85.1, C86.1, C87.1, C88.1, C89.1, C90.1, C91.1, C92.1, C93.1, C94.1, C95.1, C96.1, C97.1, C98.1, C99.1, C100.1, C101.1, C102.1, C103.1, C104.1, C105.1, C106.1, C111.1, C112.1, C113.1, C114.1, C115.1, C116.1, C117.1, C118.1, C119.1, C122.2, C123.2, C124.2, C132.1, C134.1, C135.1, C137.1, C138.1, C139.1, C140.1, C141.1, J1.3, J1.4, J6.1, J6.2, J6.5, J6.8, J6.9, J6.13, J6.14, J6.17, J6.20, J6.21, J6.25, J6.26, J6.27, J6.29, J6.32, J6.33, J6.38, J6.39, J6.42, J6.45, J6.48, J6.51, J6.54, J6.57, J6.60, J6.63, J6.66, J6.69, J6.72, J6.75, J6.78, J6.81, J6.84, J6.87, J6.90, J6.93, J6.96, J6.99, J6.102, J6.105, J6.107, J6.108, J6.109, J6.110, J8.11, J8.13, J8.15, J8.17, J8.19, J8.21, J8.23, J8.24, J8.25, J8.26, J8.27, J8.28, J8.29, J8.30, J8.32, J8.33, J8.38, J8.39, J8.40, J8.44, J8.45, J8.48, J8.51, J8.52, J8.56, J8.57, J8.60, J8.63, J8.64, J8.67, J8.68, J8.71, J8.72, J8.75, J8.76, J8.79, J8.80, J8.83, J8.84, J8.87, J8.88, J8.91, J8.92, J8.95, J8.96, J8.99, J8.100, J8.103, J8.104, J8.105, J8.106, J8.107, J8.108, J8.109, J8.110, R5.1, R8.2, R10.1, R12.2, R13.1, R15.2, R18.2, R25.1, R26.1, R34.2, R40.2, U1.5 (SGND), U1.9 (SGND), U1.14 (PGND), U1.EP, U2.5 (GND), U4.11 (RFB), U4.12 (CONFIG0), U4.13 (CONFIG1), U4.15 (RES0), U4.16 (RES1), U4.18 (RES2), U4.49 (EPAD), U6.7 (GND), U7.7 (GND), U8.33 (PAD), U9.6 (GND_CP), U9.7 (GND), U9.13 (GND), U11.3 (GND), U11.6 (GND)
unnamed: C2.2, U1.6 (SS)
unnamed: C3.2, D2.1 (K), U1.12 (BST)
unnamed: C5.2, C6.1, R3.2
unnamed: C19.2, R16.1, U3.3 (VREG5)
unnamed: C21.1, D6.1 (K), U3.8 (BOOT)
unnamed: C22.2, U3.4 (SS)
unnamed: C23.1, R17.2, R18.1, U3.2 (FB)
unnamed: C39.2, U8.1 (DVDD), U8.2 (CEXT)
unnamed: C40.1, U8.9 (XO), Y1.2
unnamed: C41.1, U8.10 (XI), Y1.1
unnamed: C42.1, R20.2, R21.2
unnamed: C42.2, C44.2
unnamed: C43.1, R22.2, R23.2
unnamed: C43.2, C45.2
unnamed: C47.2, U6.14 (RSTN)
unnamed: C62.2, U6.8 (VREG)
unnamed: C66.1, R28.1, U11.1 (INP)
unnamed: C66.2, R27.1, U4.20 (DOUT+)
unnamed: C67.1, R28.2, U11.2 (INN)
unnamed: C67.2, R27.2, U4.19 (DOUT-)
unnamed: C81.2, R30.2, U11.8 (OUTP)
unnamed: C82.2, R29.2, U11.7 (OUTN)
unnamed: C91.2, U9.4 (CP)
unnamed: C98.2, U7.14 (RSTN)
unnamed: C100.2, U7.8 (VREG)
unnamed: C118.2, R38.1, U13.3 (VREG5)
unnamed: C131.1, D8.1 (K), U13.8 (BOOT)
unnamed: C132.2, U13.4 (SS)
unnamed: C133.1, R39.2, R40.1, U13.2 (FB)
unnamed: Q1.1 (S), Q1.2 (S), Q1.3 (S)
unnamed: Q1.5 (D), Q1.6 (S), Q1.7 (S), Q1.8 (S)
unnamed: Q2.1 (S), Q2.2 (S), Q2.3 (S)
unnamed: Q2.5 (D), Q2.6 (S), Q2.7 (S), Q2.8 (S)
unnamed: Q5.1 (S), Q5.2 (S), Q5.3 (S)
unnamed: Q5.5 (D), Q5.6 (S), Q5.7 (S), Q5.8 (S)
unnamed: Q6.1 (S), Q6.2 (S), Q6.3 (S)
unnamed: Q6.5 (D), Q6.6 (S), Q6.7 (S), Q6.8 (S)
unnamed: R1.2, U1.7 (RON)
unnamed: R2.2, U1.8 (ILIM)
unnamed: R10.2, U6.1 (EQ)
unnamed: R11.2, R12.1, U6.4 (DC_BOOST/ENA_HS)
unnamed: R13.2, U7.1 (EQ)
unnamed: R14.2, R15.1, U7.4 (DC_BOOST/ENA_HS)
unnamed: R16.2, TP6.1, U3.5 (PGOOD)
unnamed: R19.1, U8.21 (PWDN_INT)
unnamed: R24.2, R25.2, U4.6 (IDX)
unnamed: R26.2, U4.23 (DE-EMPH)
unnamed: R31.1, U11.4 (Rvo)
unnamed: R32.2, U9.5 (EN)
unnamed: R33.1, U9.9 (SET)
unnamed: R33.2, R34.1, U9.8 (FB)
unnamed: R38.2, TP9.1, U13.5 (PGOOD)
VIN: C10.2, C11.2, J1.1, J1.2, R6.1, U2.1 (VIN)
VOUT: C8.2, C9.2, C14.1, C102.2, C103.2, C104.2, C105.2, R1.1, R9.2, U1.2 (VIN), U2.8 (VOUT)

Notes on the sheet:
PLACE ON TOP LAYER - FOR TESTING ONLY
100V UV/OV And Reverse Voltage Protection Controller With Bidirectional Circuit Breaker
LTC4368
Operating Voltage Range: 2.5V - 60V +/- 1.5% Overvoltage Protection: 100V Reverse Supply Protection: -40V

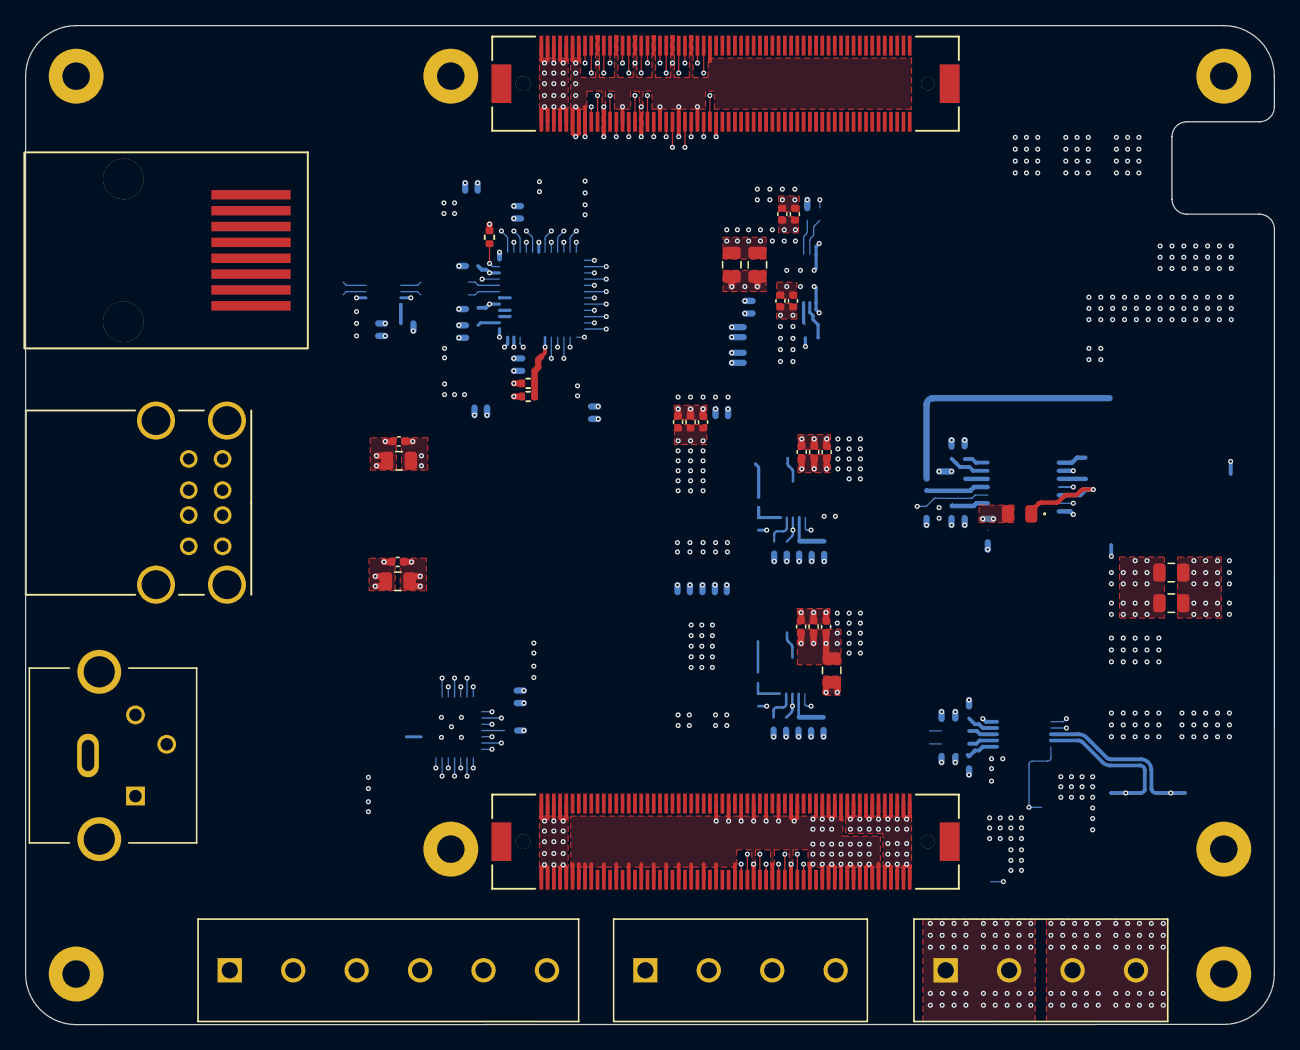
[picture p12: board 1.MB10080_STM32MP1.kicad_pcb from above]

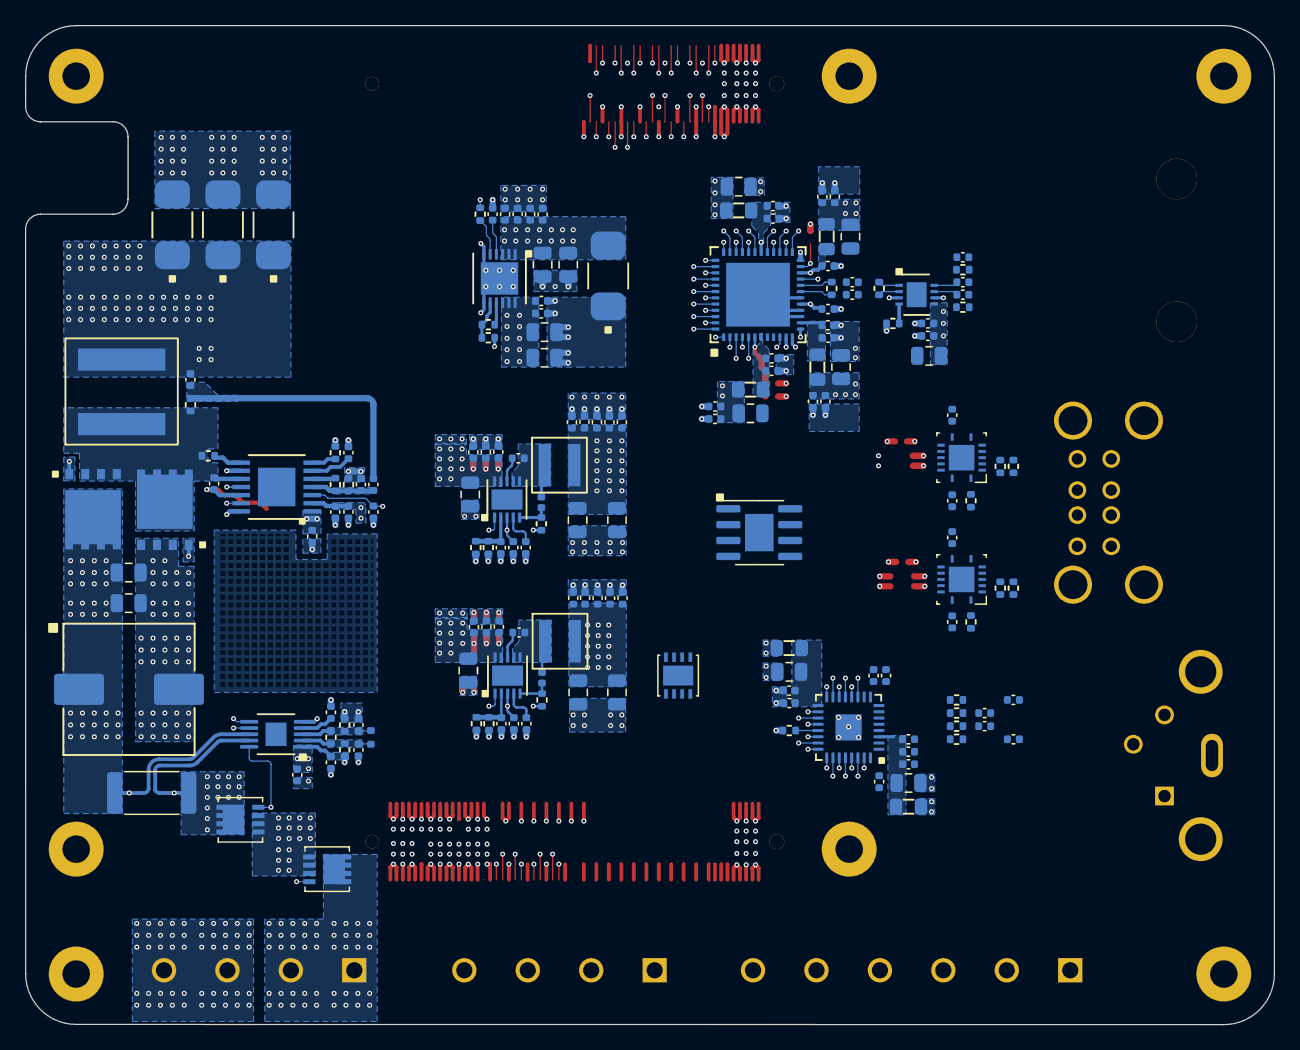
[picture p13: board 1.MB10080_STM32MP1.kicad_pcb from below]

Board: 6 copper layers, 100.0 x 80.0 mm, 212 parts (171 on the bottom side), 105 nets.

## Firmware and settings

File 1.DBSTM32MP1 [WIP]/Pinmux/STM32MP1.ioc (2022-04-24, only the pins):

Mcu.UserName=STM32MP157AAAx
PA0.Signal=ETH1_CRS
PA1.Signal=ETH1_RX_CLK
PA10.Signal=USB_OTG_HS_ID
PA11.Signal=FDCAN1_RX
PA12.Signal=FDCAN1_TX
PA13.GPIO_Label=LED2
PA13.Signal=GPIO_Output
PA14.GPIO_Label=LED1
PA14.Signal=GPIO_Output
PA15.Signal=CEC
PA2.Signal=ETH1_MDIO
PA3.Signal=ETH1_COL
PA4.Signal=COMP_DAC11_group
PA5.Signal=COMP_DAC12_group
PA7.Signal=ETH1_RX_DV
PA8.Signal=SDMMC2_D4
PA9.Signal=SDMMC2_D5
PB0.Signal=ETH1_RXD2
PB10.Signal=USART3_TX
PB11.Signal=ETH1_TX_EN
PB12.Signal=USART3_RX
PB13.Signal=USART3_CTS
PB14.Signal=SDMMC2_D0
PB15.Signal=SDMMC2_D1
PB2.GPIO_Label=VCP
PB2.Signal=UART4_RX
PB3.Signal=SDMMC2_D2
PB4.Signal=SDMMC2_D3
PB6.Signal=QUADSPI_BK1_NCS
PB7.GPIO_Label=RESERVED_RST?
PB7.Signal=GPIO_Output
PC0.Signal=QUADSPI_BK2_NCS
PC1.Signal=ETH1_MDC
PC10.GPIO_Label=RESERVER_RST?
PC10.Signal=GPIO_Output
PC11.Signal=SDMMC1_D3
PC12.Signal=SDMMC1_CK
PC13.Signal=SharedStack_PC13
PC14-OSC32_IN.Signal=RCC_OSC32_IN
PC15-OSC32_OUT.Signal=RCC_OSC32_OUT
PC2.Signal=ETH1_TXD2
PC3.Signal=ETH1_TX_CLK
PC4.Signal=ETH1_RXD0
PC5.Signal=ETH1_RXD1
PC8.Signal=SDMMC1_D0
PC9.Signal=SDMMC1_D1
PD0.Signal=SDMMC3_CMD
PD1.Signal=SDMMC3_D0
PD10.Signal=LTDC_B3
PD12.Signal=SharedStack_PD12
PD14.GPIO_Label=Generic IO
PD14.Signal=GPIO_Output
PD15.GPIO_Label=Generic IO
PD15.Signal=GPIO_Output
PD2.Signal=SDMMC1_CMD
PD3.Signal=SDMMC2_D7
PD4.Signal=SDMMC3_D1
PD5.Signal=SDMMC3_D2
PD6.GPIO_Label=Generic IO
PD6.Signal=GPIO_Output
PD7.Signal=SDMMC3_D3
PD8.GPIO_Label=Generic IO
PD8.Signal=GPIO_Output
PD9.Signal=GPXTI9
PE0.Signal=DCMI_D2
PE1.Signal=DCMI_D3
PE11.Signal=SPI4_NSS
PE12.Signal=SPI4_SCK
PE13.Signal=SPI4_MISO
PE14.Signal=SPI4_MOSI
PE15.Signal=LTDC_R7
PE2.Signal=ETH1_TXD3
PE3.Signal=SDMMC2_CK
PE5.Signal=SDMMC2_D6
PE6.Signal=SDMMC1_D2
PF0.Signal=SDMMC3_CKIN
PF1.Signal=SDMMC3_CDIR
PF10.Signal=QUADSPI_CLK
PF14.Signal=I2C1_SCL
PF15.Signal=I2C1_SDA
PF2.Signal=SDMMC3_D0DIR
PF3.Signal=ETH1_TX_ER
PF4.Signal=SDMMC3_D123DIR
PF5.GPIO_Label=RESERVED_RST?
PF5.Signal=GPIO_Output
PF6.Signal=QUADSPI_BK1_IO3
PF7.Signal=QUADSPI_BK1_IO2
PF8.Signal=QUADSPI_BK1_IO0
PF9.Signal=QUADSPI_BK1_IO1
PG10.Signal=QUADSPI_BK2_IO2
PG11.GPIO_Label=VCP
PG11.Signal=UART4_TX
PG12.Signal=LTDC_B1
PG13.Signal=ETH1_TXD0
PG14.Signal=ETH1_TXD1
PG15.Signal=SDMMC3_CK
PG4.Signal=ETH1_GTX_CLK
PG6.Signal=SDMMC2_CMD
PG7.Signal=QUADSPI_BK2_IO3
PG8.Signal=ETH1_CLK
PH0-OSC_IN.Signal=RCC_OSC_IN
PH1-OSC_OUT.Signal=RCC_OSC_OUT
PH10.Signal=SharedStack_PH10
PH11.Signal=SharedStack_PH11
PH12.Signal=SharedStack_PH12
PH13.Signal=SharedStack_PH13
PH14.Signal=SharedStack_PH14
PH15.Signal=DCMI_D11
PH2.Signal=QUADSPI_BK2_IO0
PH3.Signal=QUADSPI_BK2_IO1
PH4.Signal=I2C2_SCL
PH5.Signal=I2C2_SDA
PH7.Signal=ETH1_RXD3
PH8.Signal=SharedStack_PH8
PH9.Signal=DCMI_D0
PI0.Signal=SharedStack_PI0
PI1.Signal=SharedStack_PI1
PI10.Signal=ETH1_RX_ER
PI11.Signal=I2S_CKIN
PI12.Signal=LTDC_HSYNC
PI13.Signal=LTDC_VSYNC
PI14.Signal=LTDC_CLK
PI15.Signal=LTDC_R0
PI2.Signal=SharedStack_PI2
PI3.Signal=SharedStack_PI3
PI4.Signal=DCMI_D5
PI5.Signal=SharedStack_PI5
PI6.Signal=SharedStack_PI6
PI7.Signal=DCMI_D7
PI8.Signal=SharedStack_PI8
PJ0.Signal=LTDC_R1
PJ1.Signal=LTDC_R2
PJ10.Signal=LTDC_G3
PJ12.Signal=LTDC_B0
PJ13.Signal=LTDC_G4
PJ14.Signal=LTDC_B2
PJ2.Signal=LTDC_R3
PJ3.Signal=LTDC_R4
PJ4.GPIO_Label=Generic IO
PJ4.Signal=GPIO_Output
PJ5.GPIO_Label=Generic IO
PJ5.Signal=GPIO_Output
PJ6.GPIO_Label=Generic IO
PJ6.Signal=GPIO_Output
PJ7.Signal=LTDC_G0
PJ8.Signal=LTDC_G1
PJ9.GPIO_Label=Generic IO
PJ9.Signal=GPIO_Output
PK0.Signal=SharedStack_PK0
PK1.Signal=TIM8_CH3N
PK2.Signal=SharedStack_PK2
PK3.Signal=LTDC_B4
PK4.Signal=LTDC_B5
PK5.Signal=LTDC_B6
PK6.Signal=LTDC_B7
PK7.Signal=LTDC_DE
